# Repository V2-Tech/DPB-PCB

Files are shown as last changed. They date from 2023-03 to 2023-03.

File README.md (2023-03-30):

<h1 align="center">Dynamic Propeller Balancer - PCBs</h1><br>

<div align="center">
    <a data-flickr-embed="true" href="https://www.flickr.com/photos/198071258@N08/52781599932/in/dateposted-public/" title="DPB-PCB_v1">DPB-PCB_v1
    </a>
</div>
<br>

## :mag: Description

Under development...

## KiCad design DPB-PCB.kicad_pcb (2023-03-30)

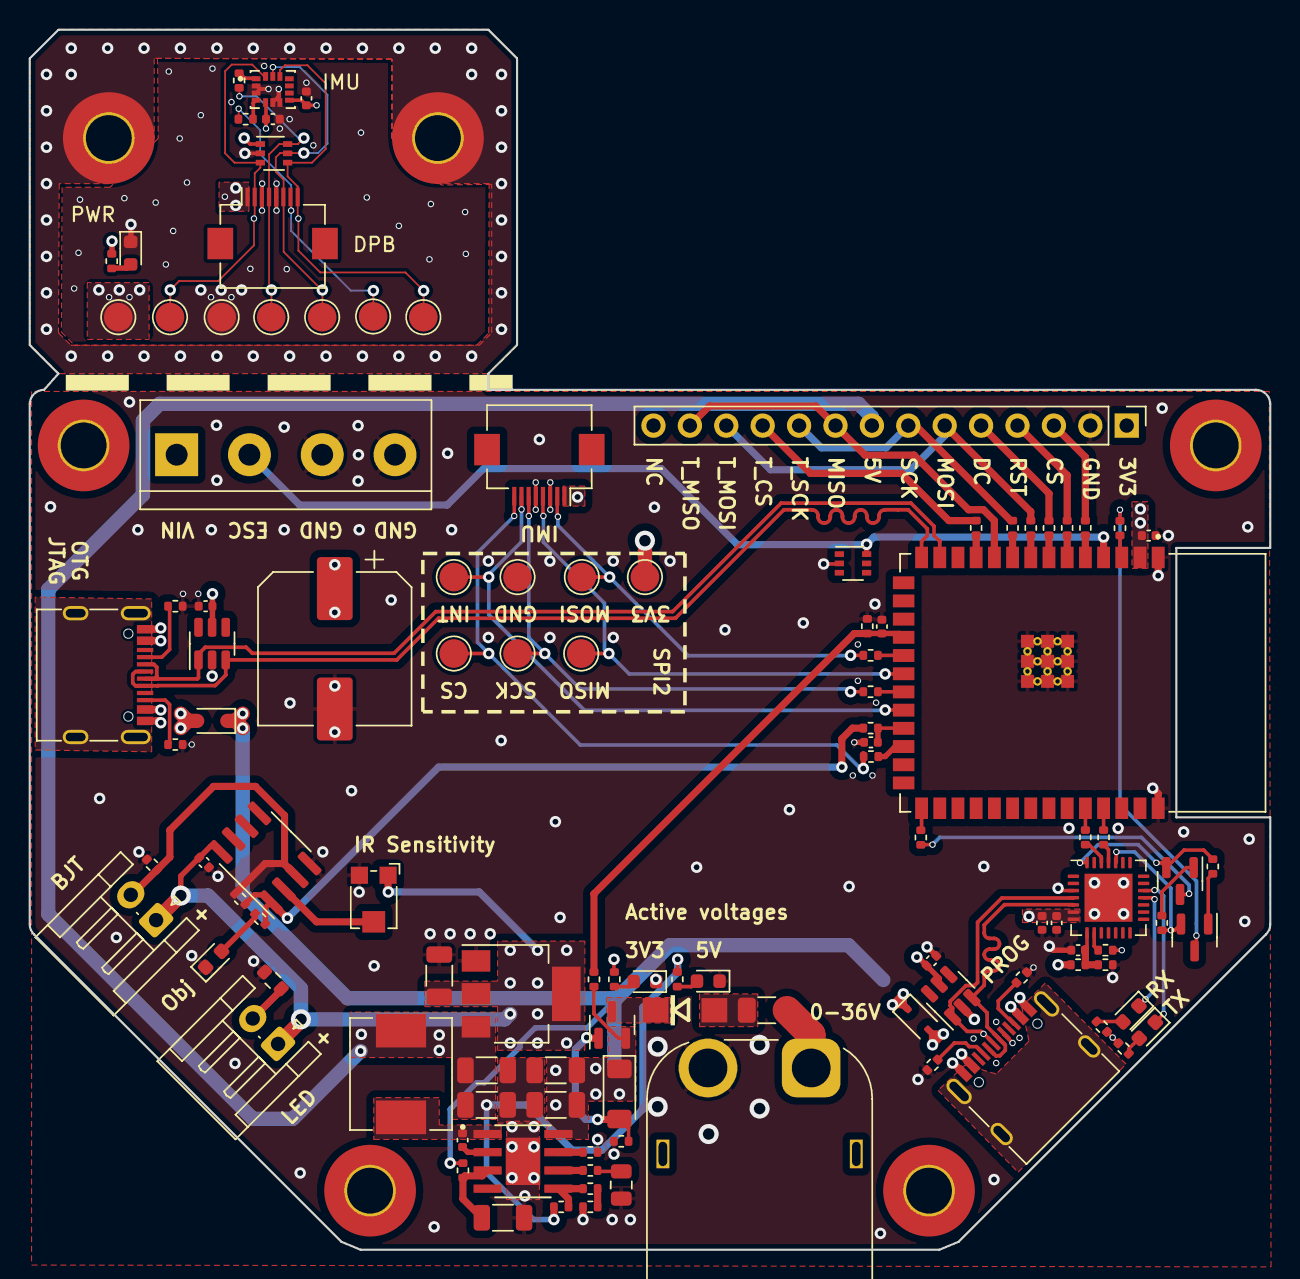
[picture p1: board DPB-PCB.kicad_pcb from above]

Board: 4 copper layers, 86.6 x 85.1 mm, 118 parts (0 on the bottom side), 86 nets.

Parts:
3V1, 3V2: TestPoint_Pad_D2.0mm
C1, C2, C7, C12, C13, C15, C16, C17, C18, C19: 100n 50V; C_0402_1005Metric
C3, C4, C6, C10: 10u 50V; C_1206_3216Metric
C5: 2n2 50V; C_0805_2012Metric
C8, C9: 22u 10V; C_1206_3216Metric
C11, C14: 10u 6V3; C_0402_1005Metric
C21: 470uf 35V; CP_Elec_10x14.3
CS1, CS2: TestPoint_Pad_D2.0mm
D1, D11: LED_GREEN; LED_0603_1608Metric
D2: SS54; DO-214AC
D3, D7: LED_BLUE; LED_0603_1608Metric
D4: BZV55B5V6; D_MiniMELF
D5, D6: 1N5819WS; D_SOD-323
D8: LED_YLW; LED_0603_1608Metric
D9, D12: SMF05CT1G; SOT-363_SC-70-6
D10: LED_YELLOW; LED_0603_1608Metric
F1: 60V 120mA; Fuse_1206_3216Metric
GND1, GND2: TestPoint_Pad_D2.0mm
H1, H2, H3, H4, H5, H6: M3; MountingHole_3.2mm_M3_Pad_TopBottom
INT1, INT2: TestPoint_Pad_D2.0mm
J1: USB_C_Prog; USB_C_Receptacle_G-Switch_GT-USB-7010ASV
J2: LCD_Conn; PinHeader_1x14_P2.54mm_Vertical
J3, J9: IMU_FFC_Conn; Hirose_FH12-8S-0.5SH_1x08-1MP_P0.50mm_Horizontal
J4: IR_SENSOR; JST_EH_S2B-EH_1x02_P2.50mm_Horizontal
J5: ESC_Conn; TerminalBlock_bornier-4_P5.08mm
J6: IR_LED; JST_EH_S2B-EH_1x02_P2.50mm_Horizontal
J7: XT60 - M; AMASS_XT60PW-M_1x02_P7.20mm_Horizontal
J8: USB_C_OTG; USB_C_Receptacle_G-Switch_GT-USB-7010ASV
L1: 6u8; L_Chilisin_BMRx00060630
MISO1, MISO2: TestPoint_Pad_D2.0mm
MOSI1, MOSI2: TestPoint_Pad_D2.0mm
Q1: AO3401A; SOT-23
Q2, Q3: MMBT5551; SOT-23
R1, R4, R5, R6, R7, R8, R9, R41, R42: 47; R_0402_1005Metric
R2, R3: 100; R_0402_1005Metric
R10, R12, R14, R29, R30, R33, R38, R39, R40: 1k; R_0402_1005Metric
R11, R19, R21, R22, R37: 10k; R_0402_1005Metric
R13: 3k3; R_0402_1005Metric
R15: 33k; R_0402_1005Metric
R16: 5k6; R_0402_1005Metric
R17: 680; R_0402_1005Metric
R18: 24k; R_0402_1005Metric
R20: 130k; R_0402_1005Metric
R23, R24: 0; R_0402_1005Metric
R25, R26, R34, R35: 5k1; R_0402_1005Metric
R27: 56k; R_0402_1005Metric
R28: 120k; R_0402_1005Metric
R31, R32: 10; R_0402_1005Metric
R36: 100; R_0603_1608Metric
R43: 100k; R_0402_1005Metric
RV1: 10k; Potentiometer_Bourns_TC33X_Vertical
SCK1, SCK2: TestPoint_Pad_D2.0mm
U1: ESP32-S3-WROOM-1-N4R2; XCVR_ESP32-S3-WROOM-1-N4R2
U2: RT7272BGSP; SOIC127P599X175-9N
U3: AMS1117-3.3; SOT-223-3_TabPin2
U4, U6: USBLC6-4SC6; SOT-23-6
U5: CP2102N-Axx-xQFN28; QFN-28-1EP_5x5mm_P0.5mm_EP3.35x3.35mm
U7: LM358; SOIC-8_3.9x4.9mm_P1.27mm
U8: LSM6DSLTR; PQFN50P300X250X86-14N

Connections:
+3.3V: 3V1.1, C1.1, C10.1, C13.1, C14.1, C16.1, J2.1, J3.1, J4.1, J6.1, R14.2, R29.1, R30.2, R33.2, RV1.1, U1.2 (3V3), U3.2 (VO), U5.6 (VDD), U5.7 (VREGIN), U7.8 (V+)
+5V: C8.1, C9.1, J2.8, L1.2, R10.2, R15.1, U3.3 (VI)
+VDC: C21.1, F1.1, J5.1, J7.1
/BOOT: R24.2, U1.27 (IO0)
/EN: R23.2, U1.3 (EN)
/GPIO5: R1.1, U1.5 (IO5)
/GPIO6: R2.1, U1.6 (IO6)
/GPIO7: R3.1, U1.7 (IO7)
/GPIO11: R4.1, U1.19 (IO11)
/GPIO13: R5.1, U1.21 (IO13)
/GPIO15: R6.1, U1.8 (IO15)
/GPIO16: R7.1, U1.9 (IO16)
/GPIO18: R8.2, U1.11 (IO18)
/GPIO47: R9.2, U1.24 (IO47)
/IMU/3V3: 3V2.1, C18.1, C19.1, D12.1 (K), J9.1, R40.2, U8.5 (VDDIO), U8.8 (VDD)
/IMU/CS: CS2.1, D12.4 (K), J9.8, U8.12 (CS)
/IMU/INT1: INT2.1, J9.7, R42.1
/IMU/MISO: D12.6 (K), J9.4, MISO2.1, R41.2
/IMU/MOSi: D12.3 (K), J9.2, MOSI2.1, U8.14 (SDA)
/IMU/SCK: D12.5 (K), J9.6, SCK2.1, U8.13 (SCL)
/Power Supply/BOOT: C7.2, U2.2 (BOOT)
/Power Supply/COMP: R18.1, U2.6 (COMP)
/Power Supply/EN: C6.1, R19.2, U2.3 (EN)
/Power Supply/FB: R15.2, R16.1, U2.5 (FB)
/Power Supply/SW: C7.1, L1.1, U2.1 (SW)
/RXD0: R31.2, U1.36 (RXD0)
/TXD0: R32.2, U1.37 (TXD0)
/USB/D+: J1.A6 (D+), J1.B6 (D+), U4.1 (I/O1), U5.4 (D+)
/USB/D-: J1.A7 (D-), J1.B7 (D-), U4.3 (I/O2), U5.5 (D-)
/USB/DTR: Q3.2 (E), R21.1, U5.28 (~DTR)
/USB/RTS: Q2.2 (E), R22.1, U5.24 (~RTS)
/USB/RXD: R32.1, U5.25 (RXD)
/USB/RXT: D7.1 (K), U5.18 (~RXT/GPIO.1)
/USB/TXD: R31.1, U5.26 (TXD)
/USB/TXT: D8.1 (K), U5.19 (~TXT/GPIO.0)
ESC_CMD: D9.6 (K), J5.2, U1.4 (IO4)
Earth_Protective: H5.1, H6.1
GND: C1.2, C2.2, C3.2, C4.2, C5.2, C6.2, C8.2, C9.2, C10.2, C11.2, C12.2, C13.2, C14.2, C15.2, C16.2, C17.2, C21.2, D1.1 (K), D3.1 (K), D9.2 (A), D10.1 (K), GND1.1, J1.A1 (GND), J1.A12 (GND), J1.B1 (GND), J1.B12 (GND), J2.2, J3.3, J3.5, J5.3, J5.4, J7.2, J8.A1 (GND), J8.A12 (GND), J8.B1 (GND), J8.B12 (GND), R12.1, R13.2, R17.2, R20.2, R25.2, R26.2, R28.2, R34.2, R35.2, R36.1, R37.1, RV1.3, U1.1 (GND), U1.40 (GND), U1.41 (GND), U2.4 (GND), U2.9 (PAD), U3.1 (GND), U4.2 (GND), U5.3 (GND), U5.29 (GND), U6.2 (GND), U7.4 (V-)
GND2: C18.2, C19.2, D11.1 (K), D12.2 (A), GND2.1, J9.3, J9.5, U8.2 (SDX), U8.3 (SCX), U8.6 (GND), U8.7 (GND)
IMU_CS: CS1.1, J3.8, R9.1
IMU_INT: INT1.1, J3.7, U1.22 (IO14)
IMU_MISO: J3.4, MISO1.1, U1.20 (IO12)
IMU_MOSI: J3.2, MOSI1.1, R4.2
IMU_SCK: J3.6, R5.2, SCK1.1
IR_INTERRUPT: C17.1, R39.2, U1.23 (IO21)
IR_LED_K: J6.2, R36.2
IR_SENSE_A: J4.2, R37.2, R43.1, U7.3 (+)
LCD_CS: J2.3, R1.2
LCD_DC: J2.5, R3.2
LCD_MISO: J2.9, J2.13, U1.10 (IO17)
LCD_MOSI: J2.6, J2.12, R6.2
LCD_RESET: J2.4, R2.2
LCD_SCK: J2.7, J2.10, R7.2
LCD_T_CS: J2.11, R8.1
unnamed: C5.1, R18.2
unnamed: D1.2 (A), R10.1
unnamed: D2.A, F1.2
unnamed: D3.2 (A), R14.1
unnamed: D4.2 (A), Q1.1 (G), R13.1
unnamed: D7.2 (A), R30.1
unnamed: D8.2 (A), R33.1
unnamed: D10.2 (A), R38.1
unnamed: D11.2 (A), R40.1
unnamed: J1.A5 (CC1), R25.1
unnamed: J1.B5 (CC2), R26.1
unnamed: J8.A5 (CC1), R34.1
unnamed: J8.B5 (CC2), R35.1
unnamed: D2.C, Q1.3 (D)
unnamed: Q2.1 (B), R21.2
unnamed: Q2.3 (C), R23.1
unnamed: Q3.1 (B), R22.2
unnamed: Q3.3 (C), R24.1
unnamed: R16.2, R17.1
unnamed: R38.2, R39.1, R43.2, U7.1
unnamed: R20.1, U2.7 (RLIM)
unnamed: C11.1, R27.2, R28.1, U5.8 (VBUS)
unnamed: R29.2, U5.9 (~RST)
unnamed: RV1.2, U7.2 (-)
unnamed: R42.2, U8.4 (INT1)
unnamed: R41.1, U8.1 (SDO/SA0)
USB_D+: J8.A6 (D+), J8.B6 (D+), U1.14 (IO20), U6.3 (I/O2)
USB_D-: J8.A7 (D-), J8.B7 (D-), U1.13 (IO19), U6.1 (I/O1)
VBUS: C12.1, D5.2 (A), J1.A4 (VBUS), J1.A9 (VBUS), J1.B4 (VBUS), J1.B9 (VBUS), R27.1, U4.5 (VBUS)
VCC: C3.1, C4.1, D4.1 (K), D5.1 (K), D6.1 (K), Q1.2 (S), R11.1, R19.1, U2.8 (VIN)
V_ADC2: C2.1, R11.2, R12.2, U1.18 (IO10)
V_USB: C15.1, D6.2 (A), J8.A4 (VBUS), J8.A9 (VBUS), J8.B4 (VBUS), J8.B9 (VBUS), U6.5 (VBUS)

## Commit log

2023-02-24 Create project
    [DPB-PCB.kicad_pcb, DPB-PCB.kicad_sch]
2023-02-24 Add ESP WROOM and USB-C
    [DPB-PCB.kicad_pcb, DPB-PCB.kicad_sch]
2023-03-14 All components have been added
    [Connections.kicad_sch, DPB-PCB.kicad_pcb, DPB-PCB.kicad_sch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]
2023-03-15 Divided project
    [DPB-PCB.kicad_pcb, DPB-PCB.kicad_sch, IO_connections.kicad_sch]
2023-03-15 Sensor board has its own project
    [SENSOR-PCB.kicad_pcb, SENSOR-PCB.kicad_sch]
2023-03-22 DPB mainboard_v1 completed
    [DPB-PCB.kicad_pcb, DPB-PCB.kicad_sch, IO_connections.kicad_sch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]
2023-03-23 Align mech holed
    [DPB-PCB.kicad_pcb]
2023-03-24 On production | V0.1
    [DPB-PCB.kicad_pcb, DPB-PCB.kicad_sch, IO_connections.kicad_sch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]
2023-03-25 Edge cut changed to avoid supplement fee
    [DPB-PCB.kicad_pcb]
2023-03-30 Add hysteresis to IR sensor. Update README file.
    [DPB-PCB.kicad_pcb, DPB-PCB.kicad_sch, IO_connections.kicad_sch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]
